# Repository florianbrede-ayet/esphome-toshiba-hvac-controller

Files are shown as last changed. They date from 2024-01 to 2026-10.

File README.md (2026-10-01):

# ESPHome Toshiba / Carrier HVAC Controller over UART / WIFI Interface
This repository contains both the hardware (kicad & production files) for an ESP32 module as well as an [ESPHome](https://esphome.io/) component to control Toshiba / Carrier RAS HVAC units independently from the Toshiba Cloud.

ESP8266 is also supported but requires custom wiring.

The device can be used as a local, low cost drop in replacement to control the AC from [Home Assistant](https://www.home-assistant.io/) or others.

Features of the component:
* All operation modes & fan modes supported
* Does not depend on external vendor cloud services
* External temperature sensor support for accurate temperature regulation (external sensor entity configurable)
* Wired and IR remotes still work, even with external temperature sensor
* Supports most special modes / merit modes like silent, fireplace, extended heating temperature range
* Support for power modes on single split units and ionizer toggle
* Additional information like fan speeds, compressor load, refrigerant / pipe temperatures
* WiFi LED toggle (on/off via UART registers 0xDE/0xDF)

Missing functionality:
* Manual defrost (probably unsupported over UART WIFI interface)
* ODU error messages (not decoded yet)
* Timer / schedules (had no interest in this functionality)
* Capability detection (all fan & merit modes will be shown, but not all might have an effect depending on the IDU)

Requirements:
* Toshiba/Carrier RAS single- or multisplit unit with built-in WIFI interface or WIFI module support (others might work as well, but untested)
* ESP32 DevKit 38 Pins (others like NodeMCU 8266 work as well but might require modifications)
* Toshiba HVAC module (see `hardware/` directory)
* ESPhome installed to flash the ESP32 initially

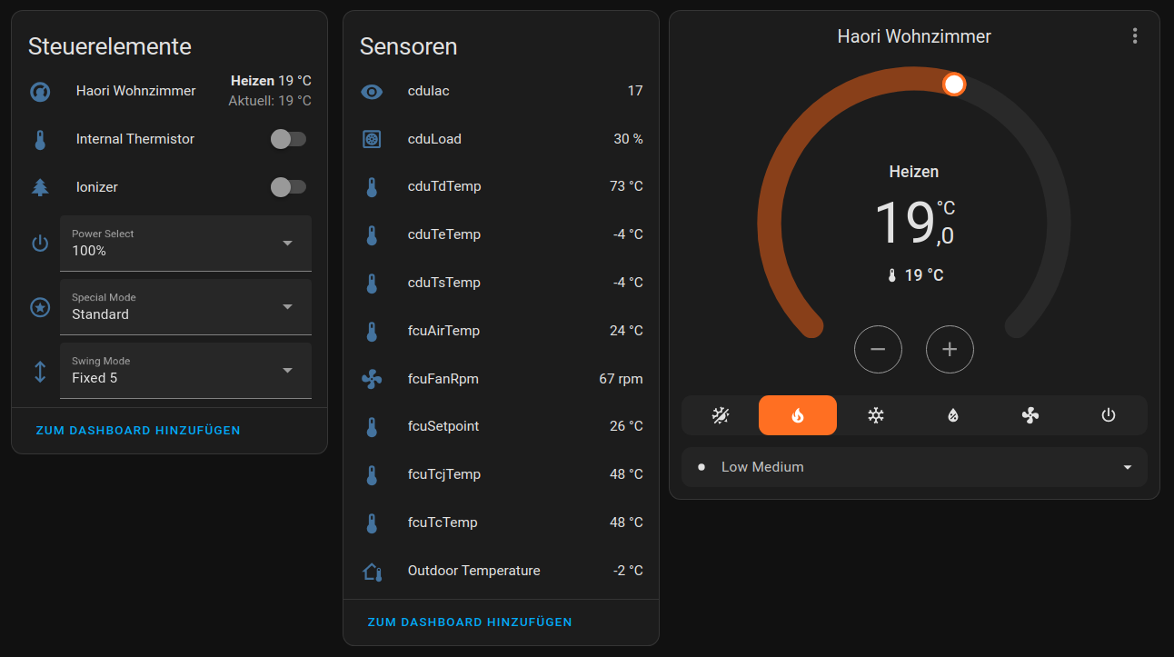
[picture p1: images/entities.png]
Home Assistant Entities


# UART Protocol
The IDU communicates over 5V `UART 9600E1`.
Messages include a length and a distinct header. Initial synchronization is ensured with a 200ms message timeout.

The protocol is relatively simple and can be observed in the `process_uart_rx` and `handle_message` functions, where the message type is identified by its length.
I've decoded most of the protocol by reading the communication with stock WRE-T00BJ10 modules and analyzing the messages against known responses from the Toshiba Cloud.

We can request registers from the IDU, we can write certain registers and also the IDU will send registers if updated externally (IDU / ODU status and changes via IR remote).

# Compatibility
Probably all Toshiba RAS units with wifi capabilities (built-in or with additional module) are supported.

The software has been tested with the following outdoor units:
* RAS-3M18U2AVG-E (Tripe-split)
* RAS-2M14U2AVG-E (Dual-split)
* RAS-25G2KVP-ND (Single-split)
And these indoor units:
* RAS-B10N4KVRG-E (Haori)
* RAS-25G2AVP-ND (Super DAISEIKAI 8)

Other units (with any compatible outdoor unit) that are almost certainly supported:
* Toshiba Seiya
* Toshiba Shorai
* Rebranded models like *Carrier X Inverter*

# Hardware

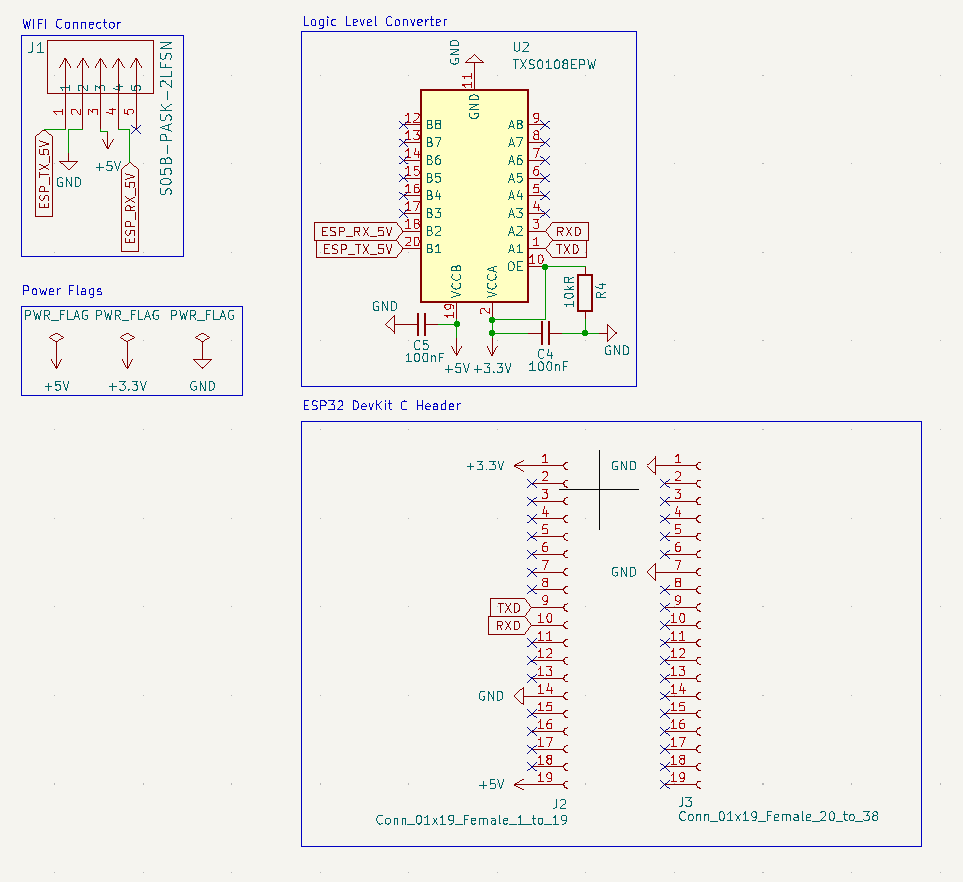
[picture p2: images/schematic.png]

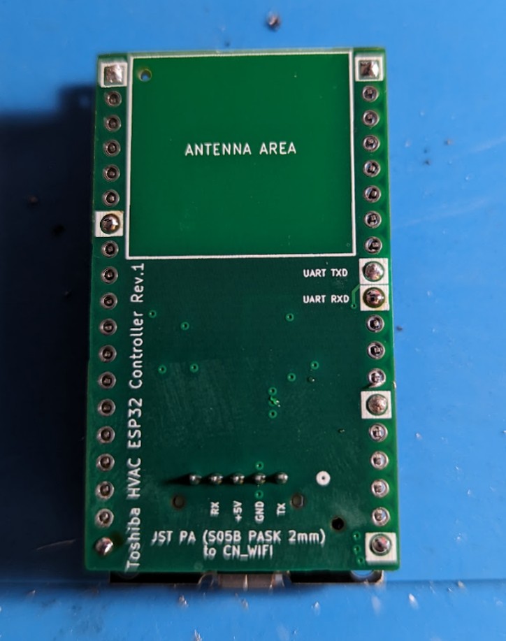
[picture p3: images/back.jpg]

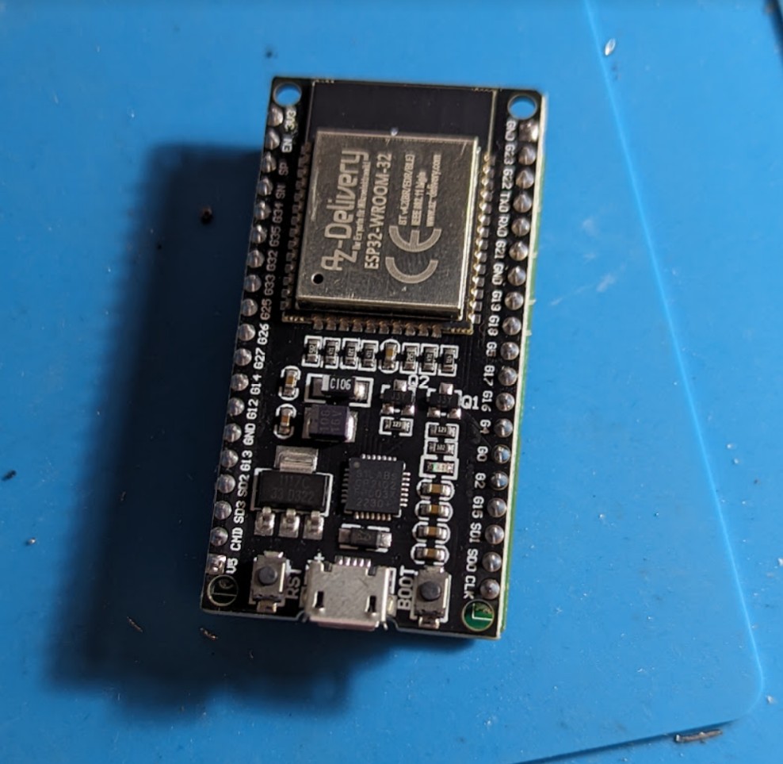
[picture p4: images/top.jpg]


The hardware needs three main components:
1) **Microcontroller**. Any ESP32-DevKit with 38 Pins should work. ESP8266 is also supported, see "ESP8266" below.
2) **Bidirectional Voltage Level Translator**. This is needed to connect to the UART interface and shift between 5V from the AC to 3.3V of the ESP32. I used a `Texas Instruments TXS0108EPWR`.
3) **Connector** Toshiba uses as JST PASK connector for the WIFI modules cable, `JST S05B-PASK-2(LF)(SN)` is the correct connector. 

External voltage regulators are not required, as the UART inteface in the indoor units works at 5V and can be directly fed into the ESP32 DevKit.

The Kicad 7 project files and ready-to-use production files (for JLCPCB or PcbWay manufacturing) are available in `hardware/` and `hardware/production` respectively.

*Attention: The Haori units with built-in WIFI modules lack height for the 2x 19p 2.54mm pin sockets. I disabled placement for the pin sockets and soldered the ESP32 on the modules:* 

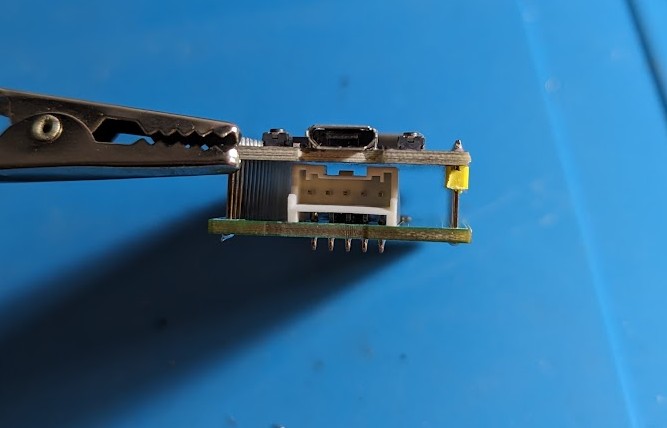
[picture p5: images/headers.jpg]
PCB Headers


# Installation
This depends on the indoor unit.
The following photos from a Toshiba Haori show how the built-in module can be replaced in a few minutes:

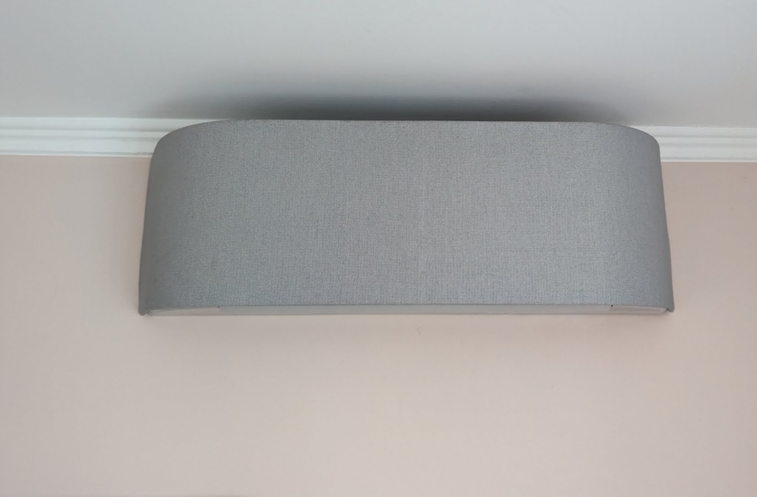
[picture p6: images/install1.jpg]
Installation 1

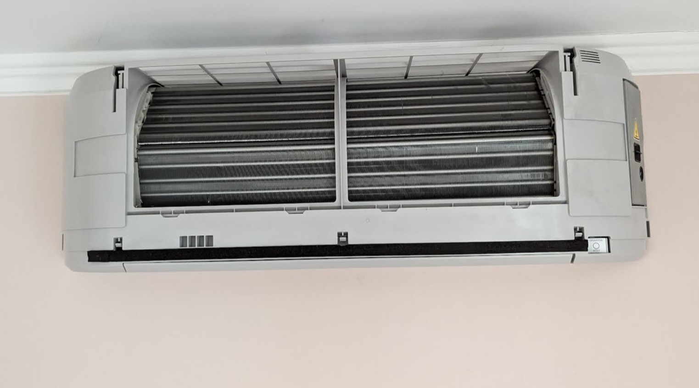
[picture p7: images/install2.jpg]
Installation 2

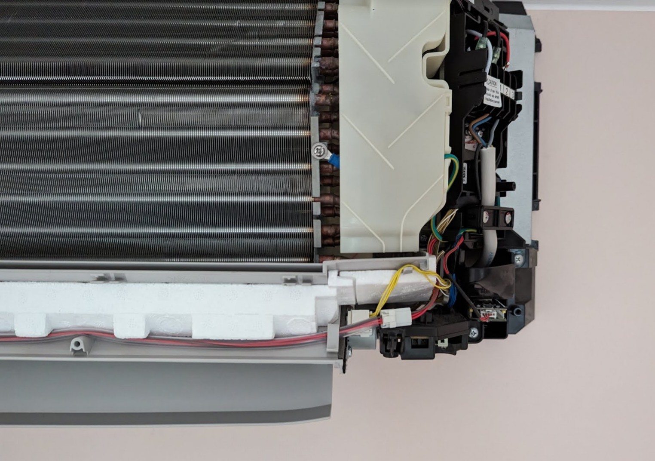
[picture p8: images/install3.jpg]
Installation 3

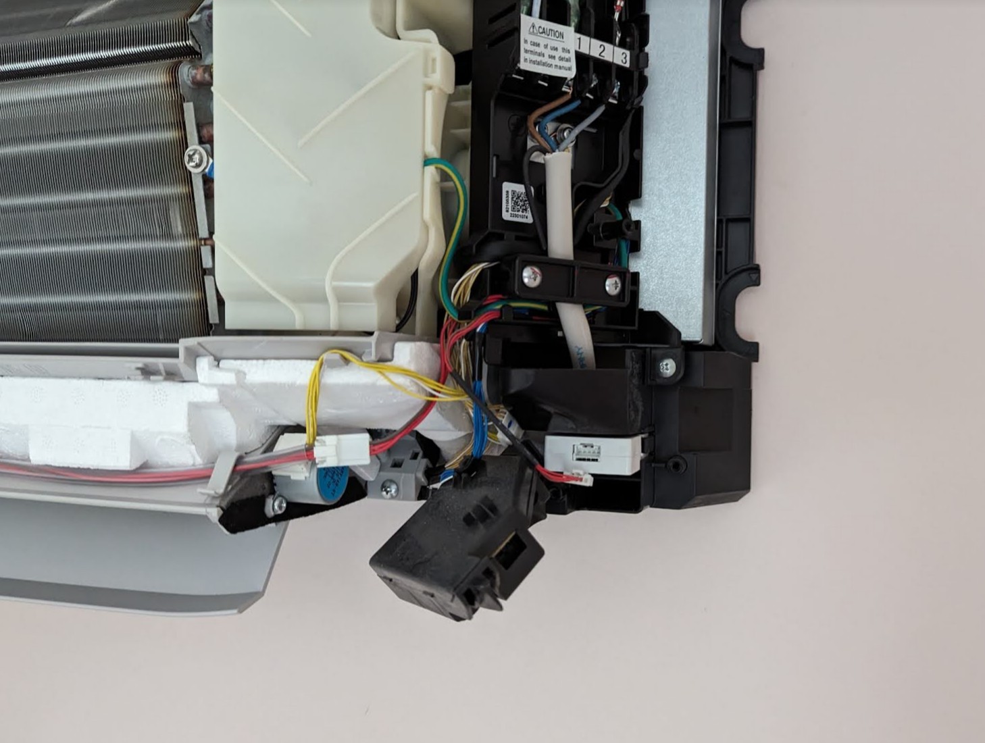
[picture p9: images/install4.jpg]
Installation 4

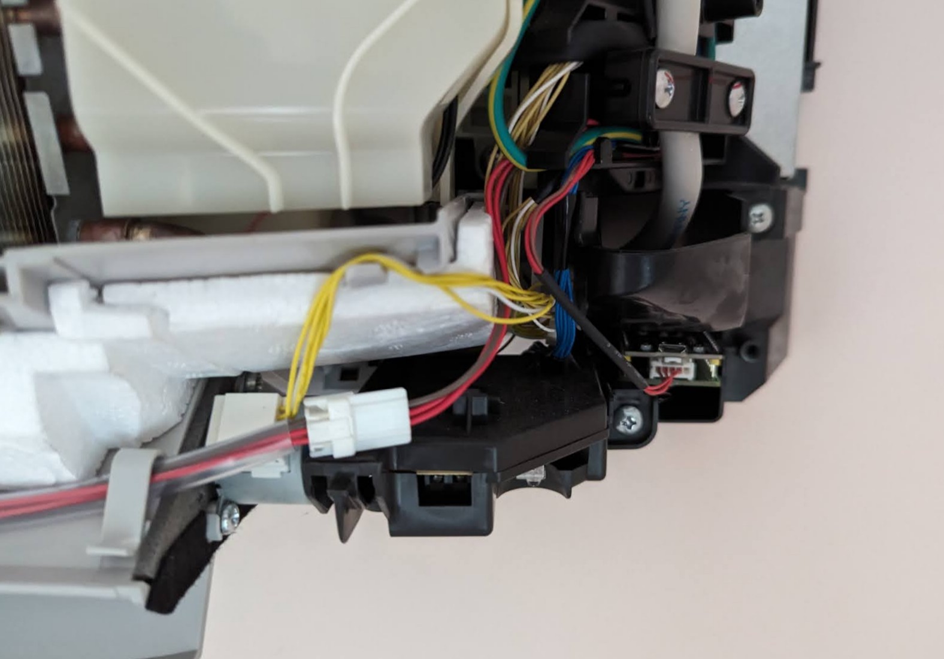
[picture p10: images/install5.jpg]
Installation 5


# Firmware

## ESPHome 2024+ (recommended)

The `toshiba_controller/` directory contains an `external_components`-based component compatible with ESPHome 2024.x and later. The legacy `platform: custom` approach no longer compiles on current ESPHome versions.

> **Note:** ESPHome 2026.5.0 removed the deprecated `ClimateTraits::set_supports_*` accessors in favor of `add_feature_flags()`/`has_feature_flags()`. This component has been updated accordingly and is compatible with ESPHome 2026.5.0 and later (as well as 2024.x/2025.x).

To use the component:
1. Clone this repository and navigate to the `esphome` directory.
2. Install ESPHome: https://esphome.io/guides/installing_esphome.html
3. Copy `template_v3.yaml` to (for example) `toshiba-livingroom.yaml` and fill in your WiFi credentials, API key, and temperature sensor entity ID.
4. Connect the ESP32 module via USB (first flash only; subsequent updates use OTA).
5. Run `esphome run toshiba-livingroom.yaml`.
6. Add the device in Home Assistant (Settings → Devices & Services).

## Migrating from Legacy (`base.yaml` / `platform: custom`)

If you are upgrading from the old `base.yaml` include with `platform: custom`, the main changes are:

1. **Remove the `<<: !include base.yaml`** line and the `includes: [toshiba-controller.h]` reference.
2. **Add `external_components`** pointing to the `toshiba_controller/` directory (see `template_v3.yaml`).
3. **Replace the `climate: platform: custom` block** with a top-level `toshiba_controller:` block.
4. **Replace `sensor: platform: custom`** with `sensor: platform: toshiba_controller` (sensor names are preserved).
5. **Replace `switch: platform: custom`** with `switch: platform: toshiba_controller` for Internal Thermistor and Ionizer.
6. **Split the Special Mode select** into three separate selects: Special Mode, Silent Mode, and Fireplace (the old config had all modes in a single flat list).
7. **Optionally add** the new WiFi LED template switch.

See `template_v3.yaml` for a complete example of the new configuration format.

## Legacy ESPHome (< 2024)

If you are still on an older ESPHome version, use `template.yaml` with the single-file `toshiba-controller.h` from an [older release](https://github.com/florianbrede-ayet/esphome-toshiba-hvac-controller/tree/90621ac). Note that `platform: custom` has been removed in ESPHome 2024.

## Logs

```bash
esphome logs toshiba-livingroom.yaml
```

# ESP8266
ESP8266 is supported but requires custom wiring. Use `template_v3.yaml` as a starting point and adjust the board, UART pins (`GPIO1` TX / `GPIO3` RX), and framework accordingly.
A bidirectional logic level converter must be connected to the UART pins.

The NodeMCU can be powered directly from the indoor unit's UART connector 5V Pin 3 through VIN.

# FAQ
## Smart Thermostat / Internal Thermistor
If the binary switch `Internal Thermistor` is disabled in Home Assistant, the external temperature sensor supplied in the `yaml` configuration will be used for the room temperature.

Most ACs suffer from poor thermistor placement (high position, heat draft) and Toshiba does not support external thermistors over UART.

This requires a more complex regulation in the `smart_thermostat_control` function which can be fine tuned with the `smart_thermostat_multiplier` config parameter.

A recommended value is `4`, which results in a regulation accuracy of around `+/- 0.25°K`.
Higher values increase the accuracy at the cost of more compressor cycles.

## ODU parameters (`cduIac` & `cduLoad`)
The parameters `cduIac` and `cduLoad` seem off at first however, the values are identical to Toshiba's own parameters.

The `cduLoad` is internally called `cduCompHz` by Toshiba and has a range from 0-170.
Since the value has an identical range regardless of the compressor, does not match the actual compressor frequency and is independant for each indoor unit, I converted the number to a percentage which correlates well with the requested power for the IDU.

The same is true for `cduIac` which is closely following `cduLoad`.
My best guess is that `cduLoad` is the heat request for the IDU and `cduIac` is related to the IDU's EEV.

# Credits
* Inspiration & initial protocol description from [ToshibaCarrierHvac](https://github.com/ormsport/ToshibaCarrierHvac)
* ESPhome component structure from [esphome-lg-controller](https://github.com/JanM321/esphome-lg-controller)

# License

This project is released under the MIT License.

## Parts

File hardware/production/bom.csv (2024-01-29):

Designator | Footprint | Quantity | Value | LCSC Part #
C4, C5 | 0402 | 2 | 100nF | C1525
J1 | CONN_S05B-PASK-2_JST | 1 | S05B-PASK-2LFSN | C489718
J2 | PinSocket_1x19_P2.54mm_Vertical | 1 | Conn_01x19_Female_1_to_19 | C2932678
J3 | PinSocket_1x19_P2.54mm_Vertical | 1 | Conn_01x19_Female_20_to_38 | C2932678
R4 | 0603 | 1 | 10kR | C25804
U2 | TSSOP-20_4.4x6.5mm_P0.65mm | 1 | TXS0108EPW | C17206

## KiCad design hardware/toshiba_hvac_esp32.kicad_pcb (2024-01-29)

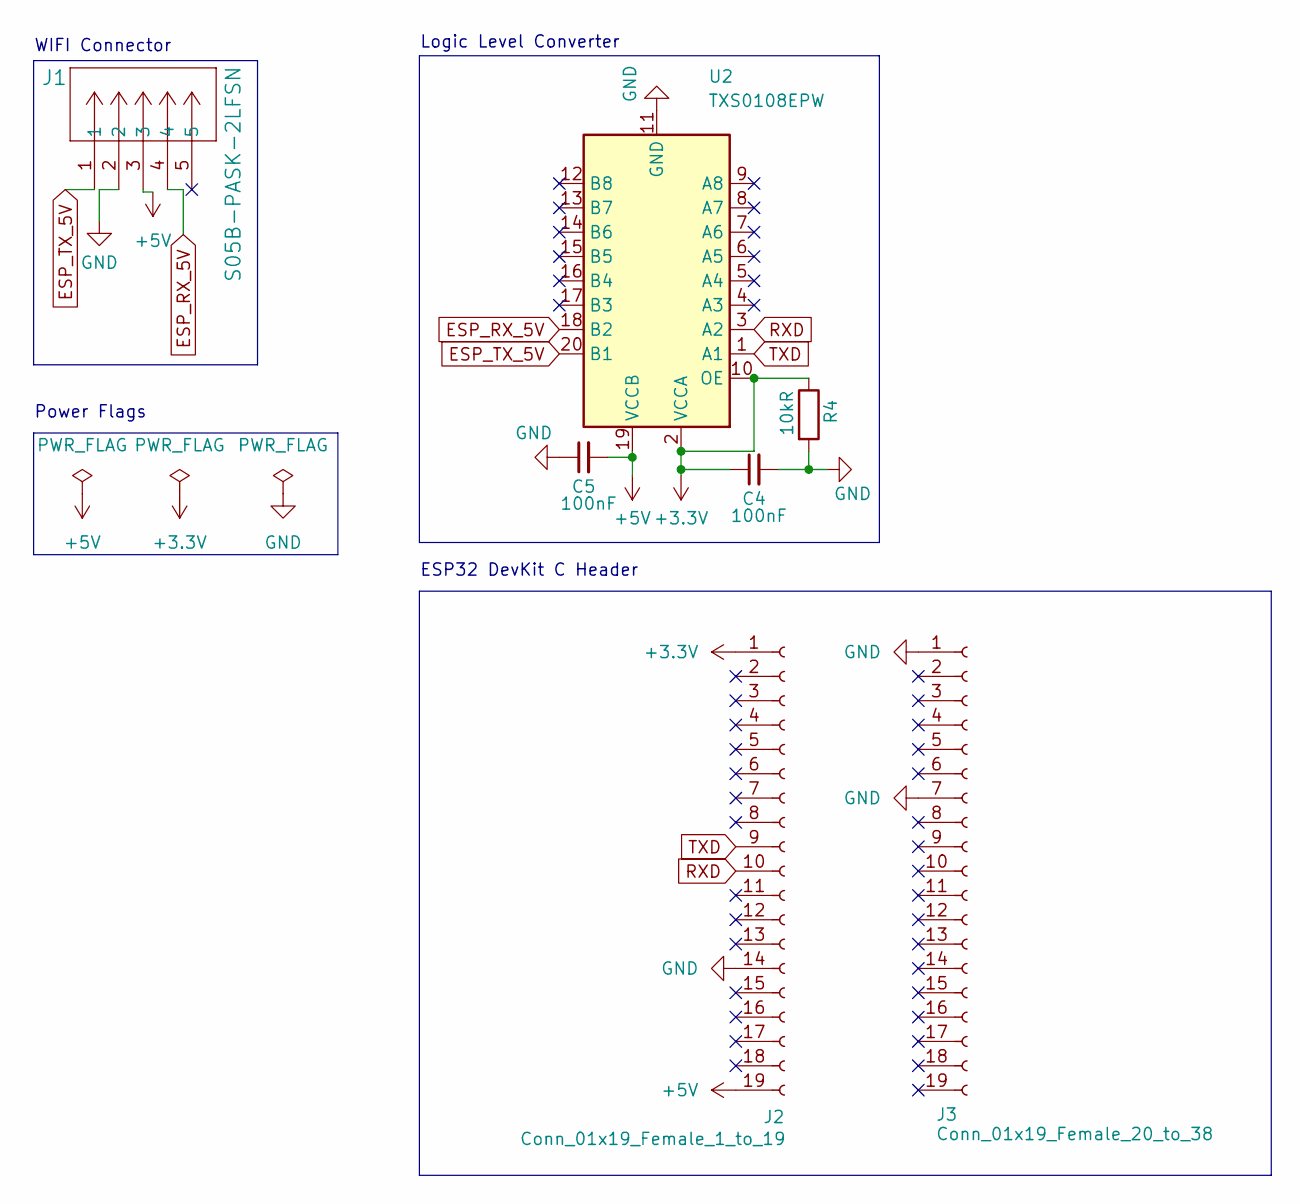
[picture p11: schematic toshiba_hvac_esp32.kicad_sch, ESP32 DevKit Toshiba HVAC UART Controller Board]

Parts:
C4, C5: 100nF; C_0402_1005Metric; LCSC C1525
J1: S05B-PASK-2LFSN; CONN_S05B-PASK-2_JST; LCSC C489718
J2: Conn_01x19_Female_1_to_19; PinSocket_1x19_P2.54mm_Vertical; LCSC C2932678
J3: Conn_01x19_Female_20_to_38; PinSocket_1x19_P2.54mm_Vertical; LCSC C2932678
R4: 10kR; R_0603_1608Metric; LCSC C25804
U2: TXS0108EPW; TSSOP-20_4.4x6.5mm_P0.65mm; LCSC C17206

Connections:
+3.3V: C4.1, J2.1, R4.1, U2.2 (VCCA), U2.10 (OE)
+5V: C5.2, J1.3, J2.19, U2.19 (VCCB)
ESP_RX_5V: J1.4, U2.18 (B2)
ESP_TX_5V: J1.1, U2.20 (B1)
GND: C4.2, C5.1, J1.2, J2.14, J3.1, J3.7, R4.2, U2.11 (GND)
RXD: J2.10, U2.3 (A2)
TXD: J2.9, U2.1 (A1)

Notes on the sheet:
WIFI Connector
Logic Level Converter
Power Flags
ESP32 DevKit C Header

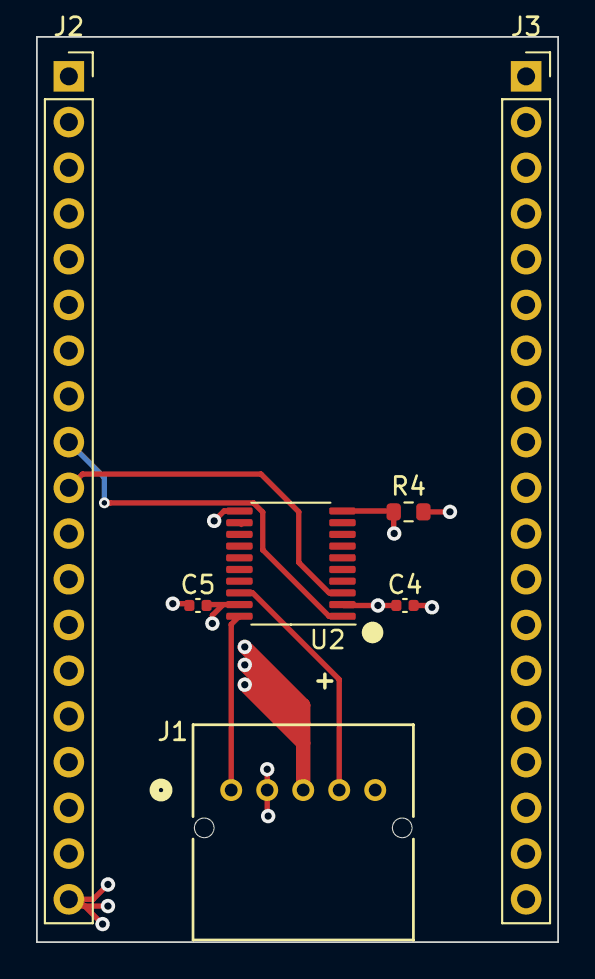
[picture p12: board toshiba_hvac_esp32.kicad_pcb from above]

Board: 4 copper layers, 29.0 x 50.3 mm, 7 parts (0 on the bottom side), 7 nets.

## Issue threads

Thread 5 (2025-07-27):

Partial work with Toshiba Seiya

Kudukin, 2025-07-27:
Using ESPHome 2024.12 I was able to run this code on 8266.
A control component appeared, turns on and off. But the blinds and fan speed control do not work. It does not show readings from various sensors. Has anyone run this code together with Seiya? What finer settings are needed?

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

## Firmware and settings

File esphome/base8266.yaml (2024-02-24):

esphome:
  name: ${deviceid}
  friendly_name: ${devicename}
  includes:
    - toshiba-controller.h

esp8266:
  board: esp01_1m

logger:
  # ESP8266 only - disable serial port logging, as the HeatPump component
  # needs the sole hardware UART on the ESP8266
  baud_rate: 0

uart:
  - id: ac_serial
    tx_pin: 1
    rx_pin: 3
    baud_rate: 9600
    parity: EVEN

sensor:
  - id: temperature_sensor
    platform: homeassistant
    internal: true
    entity_id: ${temperature_sensor_entity_id}
  - platform: custom
    lambda: |-
      return ((ToshibaController*)id(${deviceid}))->get_sensors();
    sensors:
      - name: Outdoor Temperature
        unit_of_measurement: "°C"
        icon: "mdi:home-thermometer-outline"
        device_class: "temperature"
        state_class: "measurement"
        accuracy_decimals: 0
      - name: fcuAirTemp
        unit_of_measurement: "°C"
        icon: "mdi:thermometer"
        device_class: "temperature"
        state_class: "measurement"
        accuracy_decimals: 0
      - name: fcuSetpoint
        unit_of_measurement: "°C"
        icon: "mdi:thermometer"
        device_class: "temperature"
        state_class: "measurement"
        accuracy_decimals: 0
      - name: fcuTcTemp
        unit_of_measurement: "°C"
        icon: "mdi:thermometer"
        device_class: "temperature"
        state_class: "measurement"
        accuracy_decimals: 0
      - name: fcuTcjTemp
        unit_of_measurement: "°C"
        icon: "mdi:thermometer"
        device_class: "temperature"
        state_class: "measurement"
        accuracy_decimals: 0
      - name: fcuFanRpm
        unit_of_measurement: "rpm"
        icon: "mdi:fan"
        device_class: ""
        state_class: "measurement"
        accuracy_decimals: 0
      - name: cduTdTemp
        unit_of_measurement: "°C"
        icon: "mdi:thermometer"
        device_class: "temperature"
        state_class: "measurement"
        accuracy_decimals: 0
      - name: cduTsTemp
        unit_of_measurement: "°C"
        icon: "mdi:thermometer"
        device_class: "temperature"
        state_class: "measurement"
        accuracy_decimals: 0
      - name: cduTeTemp
        unit_of_measurement: "°C"
        icon: "mdi:thermometer"
        device_class: "temperature"
        state_class: "measurement"
        accuracy_decimals: 0
      - name: cduLoad
        unit_of_measurement: "%"
        icon: "mdi:heat-pump-outline"
        device_class: ""
        state_class: "measurement"
        accuracy_decimals: 0
      - name: cduIac
        device_class: ""
        state_class: "measurement"
        accuracy_decimals: 0
  - platform: uptime
    name: Uptime

switch:
  - platform: custom
    lambda: |-
      return ((ToshibaController*)id(${deviceid}))->get_switches();
    switches:
      - name: Internal Thermistor
        on_turn_on:
          - lambda: |-
              ((ToshibaController*)id(${deviceid}))->set_internal_thermistor_switch(true);
        on_turn_off:
          - lambda: |-
              ((ToshibaController*)id(${deviceid}))->set_internal_thermistor_switch(false);
      - name: Ionizer
        on_turn_on:
          - lambda: |-
              ((ToshibaController*)id(${deviceid}))->set_ionizer_switch(true);
        on_turn_off:
          - lambda: |-
              ((ToshibaController*)id(${deviceid}))->set_ionizer_switch(false);

select:
  - platform: template
    name: Special Mode
    id: special_mode
    optimistic: true
    icon: mdi:star-circle-outline
    options:
      - "Standard"
      - "High Power"
      - "ECO"
      - "8 Degrees"
      - "Fireplace 1"
      - "Fireplace 2"
      - "Silent 1"
      - "Silent 2"
      - "Sleep Care"
      - "Floor"
      - "Comfort"
    on_value:
      - lambda: |-
          ((ToshibaController*)id(${deviceid}))->set_special_mode_select(i);
  - platform: template
    name: Swing Mode
    id: swing_mode
    optimistic: true
    icon: mdi:arrow-up-down
    options:
      - "Off"
      - "Vertical"
      - "Horizontal"
      - "Vertical & Horizontal"
      - "Fixed 1"
      - "Fixed 2"
      - "Fixed 3"
      - "Fixed 4"
      - "Fixed 5"
    on_value:
      - lambda: |-
          ((ToshibaController*)id(${deviceid}))->set_swing_mode_select(i);
  - platform: template
    name: Power Select
    id: power_select
    optimistic: true
    icon: mdi:power
    options:
      - "50%"
      - "75%"
      - "100%"
    on_value:
      - lambda: |-
          ((ToshibaController*)id(${deviceid}))->set_power_select(i);
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

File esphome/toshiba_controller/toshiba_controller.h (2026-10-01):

/**
 * @file toshiba-controller.h
 * @brief Toshiba AC controller component for ESPHome
 *
 */
#include <cmath>
#include <deque>

#include "esphome/components/climate/climate.h"
#include "esphome/components/select/select.h"
#include "esphome/components/sensor/sensor.h"
#include "esphome/components/switch/switch.h"
#include "esphome/components/uart/uart.h"
#include "esphome/core/application.h"
#include "esphome/core/component.h"
#include "esphome/core/helpers.h"
#include "esphome/core/log.h"
#include "esphome/core/version.h"  // ESPHOME_VERSION_CODE / VERSION_CODE (pulls in macros.h)

static const char* const TAG = "toshiba-controller";

#define MIN_TEMP_SETPOINT_HEATING 5
#define MIN_TEMP_SETPOINT_COOLING 17
#define MAX_TEMP_SETPOINT 30

namespace esphome {

struct ConfigSettings {
    double smart_thermostat_multiplier = 4.0;
    bool smart_thermostat_runaway_protection = false;
    bool disable_cooling_modes = false;
};

enum CustomSwitchType { SWITCH_INTERNAL_THERMISTOR = 0, SWITCH_IONIZER = 1 };

class ToshibaController;

// Custom switch. Notifies the controller when state changes in HA.
class CustomSwitch final : public switch_::Switch {
    ToshibaController* controller_{nullptr};
    CustomSwitchType type_{SWITCH_INTERNAL_THERMISTOR};

public:
    CustomSwitch() = default;

    void set_controller(ToshibaController* c) { controller_ = c; }
    void set_type(CustomSwitchType t) { type_ = t; }

    void write_state(bool state) override;

    void restore_and_set_mode(switch_::SwitchRestoreMode mode) {
        set_restore_mode(mode);
        if (auto state = get_initial_state_with_restore_mode()) {
            write_state(*state);
        }
    }
};

static constexpr const char* CUSTOM_FAN_MODE_LOW_MEDIUM = "low medium";
static constexpr const char* CUSTOM_FAN_MODE_MEDIUM_HIGH = "medium high";

enum ToshibaSwingMode {
    SWING_MODE_OFF = 0x31,
    SWING_MODE_SWING_VERTICAL = 0x41,
    SWING_MODE_SWING_HORIZONTAL = 0x42,
    SWING_MODE_SWING_VERTICAL_AND_HORIZONTAL = 0x43,
    SWING_MODE_FIXED_1 = 0x50,
    SWING_MODE_FIXED_2 = 0x51,
    SWING_MODE_FIXED_3 = 0x52,
    SWING_MODE_FIXED_4 = 0x53,
    SWING_MODE_FIXED_5 = 0x54,
    SWING_MODE_NONE = 0x00,
};

enum ToshibaCommand {
    POWER_STATE = 0x80,
    POWER_SELECT = 0x87,
    FAN_MODE = 0xA0,
    SWING_MODE = 0xA3,
    MODE = 0xB0,
    TARGET_TEMPERATURE = 0xB3,
    ROOM_TEMPERATURE = 0xBB,
    OUTDOOR_TEMPERATURE = 0xBE,
    IONIZER = 0xC7,
    WIFILED1 = 0xDE,  // variant 1: on=0x05, off=0x00
    WIFILED2 = 0xDF,  // variant 2: on=0x00, off=0x80
    SPECIAL_MODE = 0xF7,
    IDU_STATUS = 0xE4,
    ODU_STATUS = 0xE5,
};

enum ToshibaSpecialModes {
    SPECIAL_MODE_STANDARD = 0x00,
    SPECIAL_MODE_HIGH_POWER = 0x01,
    SPECIAL_MODE_ECO = 0x03,
    SPECIAL_MODE_EIGHT_DEGREES = 0x04,
    SPECIAL_MODE_FIREPLACE_1 = 0x20,
    SPECIAL_MODE_FIREPLACE_2 = 0x30,
    SPECIAL_MODE_SILENT_1 = 0x02,
    SPECIAL_MODE_SILENT_2 = 0x0A,
    SPECIAL_MODE_SLEEP_CARE = 0x05,
    SPECIAL_MODE_FLOOR = 0x06,
    SPECIAL_MODE_COMFORT = 0x07,
};

enum ToshibaState {
    STATE_ON = 0x30,
    STATE_OFF = 0x31,
};

enum ToshibaMode {
    MODE_HEAT_COOL = 0x41,
    MODE_COOL = 0x42,
    MODE_HEAT = 0x43,
    MODE_DRY = 0x44,
    MODE_FAN_ONLY = 0x45,
};

enum ToshibaFanMode {
    FAN_QUIET = 0x31,
    FAN_LOW = 0x32,
    FAN_LOW_MEDIUM = 0x33,
    FAN_MEDIUM = 0x34,
    FAN_MEDIUM_HIGH = 0x35,
    FAN_HIGH = 0x36,
    FAN_AUTO = 0x41,
};

enum ToshibaPowerSelection {
    POWER_50 = 0x32,
    POWER_75 = 0x4B,
    POWER_100 = 0x64,
};

enum ToshibaIonizer { IONIZER_ON = 0x18, IONIZER_OFF = 0x10 };

enum ToshibaSelfCleaning { SELF_CLEANING_ON = 0x18, SELF_CLEANING_OFF = 0x10 };

static const std::vector<std::vector<uint8_t>> IDU_HANDSHAKE = {
    {0x02, 0xFF, 0xFF, 0x00, 0x00, 0x00, 0x00, 0x02},
    {0x02, 0xFF, 0xFF, 0x01, 0x00, 0x00, 0x01, 0x02, 0xFE},
    {0x02, 0x00, 0x00, 0x00, 0x00, 0x00, 0x02, 0x02, 0x02, 0xFA},
    {0x02, 0x00, 0x01, 0x81, 0x01, 0x00, 0x02, 0x00, 0x00, 0x7B},
    {0x02, 0x00, 0x01, 0x02, 0x00, 0x00, 0x02, 0x00, 0x00, 0xFE},
    {0x02, 0x00, 0x02, 0x00, 0x00, 0x00, 0x00, 0xFE}};

static const std::vector<std::vector<uint8_t>> IDU_POST_HANDSHAKE = {
    {0x02, 0x00, 0x02, 0x01, 0x00, 0x00, 0x02, 0x00, 0x00, 0xFB},
    //{0x02, 0x00, 0x02, 0x00, 0x00, 0x00, 0x02, 0x00, 0x00, 0xFC}, // works as well, did not observe different
    //behaviour
    {0x02, 0x00, 0x02, 0x02, 0x00, 0x00, 0x02, 0x00, 0x00, 0xFA}};

class ToshibaController final : public climate::Climate, public Component {
    climate::ClimateTraits supported_traits_;

    esphome::uart::UARTComponent* serial_{nullptr};
    esphome::sensor::Sensor* temperature_sensor_{nullptr};
    esphome::select::Select* swing_mode_select_{nullptr};
    esphome::select::Select* special_mode_select_{nullptr};
    esphome::select::Select* silent_mode_select_{nullptr};
    esphome::select::Select* fireplace_select_{nullptr};
    esphome::select::Select* power_selection_select_{nullptr};

    uint32_t last_partial_register_request_millis_ = 0;
    uint32_t last_full_register_request_millis_ = 0;
    uint32_t last_external_temperature_sensor_control_millis_ = 0;

    CustomSwitch* switch_internal_thermistor_{nullptr};
    CustomSwitch* switch_ionizer_{nullptr};

    uint8_t recv_buf_[256] = {};
    uint32_t recv_buf_len_ = 0;
    uint32_t last_recv_millis_ = 0;

    std::vector<std::vector<uint8_t>> send_msg_queue_;
    uint32_t last_sent_millis_ = 0;

    ConfigSettings config_settings_;

    bool updating_from_ac_ = false;  // suppress on_value callbacks during AC-initiated state updates

    ToshibaState internal_power_state_ = ToshibaState::STATE_OFF;
    ToshibaFanMode internal_fan_mode_ = ToshibaFanMode::FAN_MEDIUM;
    ToshibaSwingMode internal_swing_mode_ = ToshibaSwingMode::SWING_MODE_OFF;
    ToshibaSpecialModes internal_special_mode_ = ToshibaSpecialModes::SPECIAL_MODE_STANDARD;
    ToshibaPowerSelection internal_power_selection_ = ToshibaPowerSelection::POWER_100;
    uint8_t internal_target_temperature_ = 20;

    bool is_initialized_ = false;

    int8_t internal_idu_room_temperature_ = 0;

    sensor::Sensor* sensor_outdoor_temperature_{nullptr};
    sensor::Sensor* sensor_cdu_td_temp_{nullptr};
    sensor::Sensor* sensor_cdu_ts_temp_{nullptr};
    sensor::Sensor* sensor_cdu_te_temp_{nullptr};
    sensor::Sensor* sensor_cdu_load_{nullptr};
    sensor::Sensor* sensor_cdu_iac_{nullptr};
    sensor::Sensor* sensor_fcu_air_temp_{nullptr};
    sensor::Sensor* sensor_fcu_setpoint_temp_{nullptr};
    sensor::Sensor* sensor_fcu_tc_temp_{nullptr};
    sensor::Sensor* sensor_fcu_tcj_temp_{nullptr};
    sensor::Sensor* sensor_fcu_fan_rpm_{nullptr};

    uint64_t loop_cnt_ = 0;

    uint8_t calc_checksum(uint8_t* data, uint8_t length) {
        uint8_t sum = 0;
        for (size_t i = 1; i < length; i++) {
            sum += data[i];
        }
        return (-sum) & 0xFF;
    }
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

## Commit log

2024-02-23 Adds base8266.yaml for esp8266 setup, fixes logging
    * Include base8266.yaml instead of base.yaml for 8266 setup
    * Fixed compilation issue
    [base8266.yaml, toshiba-controller.h]
2024-05-08 fixed possible uint8 over/underflows that could cause thermal runaway
    [toshiba-controller.h]
2025-03-10 fixed bug in external temperature changes (IR remote) with external temperature sensor: - external change messages are ignored - smart thermostat handling and 10s polling for current target temperatu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
    [toshiba-controller.h]
2025-03-16 fixed incorrect ECO mode spelling in publish_state (thanks to Kryobot)
    [toshiba-controller.h]
